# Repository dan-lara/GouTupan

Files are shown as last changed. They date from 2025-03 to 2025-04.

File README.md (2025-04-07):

# GouTupan



# User Guide —— GouTupan  

**Daniel, Vladislav, Xiaochen, Yulin**  

---

## Device Overview  

The system is an integrated environmental monitoring platform for agricultural greenhouses, based on an Arduino MKR WAN 1310 development board.  
Equipped with multiple specialized sensors, it enables real-time measurement of critical parameters for plant growth.  

Key features include:  
- Self-powered via solar panel with energy management circuit;  
- Waterproof design suitable for greenhouse environments with frequent irrigation;  
- Wireless data transmission via LoRaWAN;  
- Modular architecture for customized measurement points;  
- User interface: Web platform and local e-ink display for remote or on-site monitoring.  

---

## Installation and Usage Instructions  

The device transmits data using the LoRa protocol. Ensure the installation site has stable coverage from a LoRaWAN gateway.  
Without this, the following features will be unavailable: remote monitoring and historical data access.  

The system comprises four main modules:  
- **MCU Enclosure**: Contains the microcontroller and processing unit;  
- **"Mushroom" Sensor**: Measures ambient conditions;  
- **Soil Temperature & Humidity Sensor Array**;  
- **Solar Panel**: Powers the system.  

### MCU Enclosure  
Integrates an MKR WAN 1310 board, power management circuit, light sensor, and e-ink display.  
**Installation**: Position in a non-floodable area with direct ambient light exposure.  

### "Mushroom" Sensor  
Combines temperature, humidity, and gas sensors. Deploy at target measurement points.  
**Caution**: Avoid watering from below to prevent water ingress.  

### Soil Sensors  
- **Compact Probe**: Surface measurement (10 cm depth);  
- **Long Cylindrical Probe**: 50 cm length for deep soil measurements.  

### Solar Panel  
**Installation**: Place in a sunlit, elevated location to avoid water accumulation.  

### Activation  
Toggle the **side switch** on the MCU enclosure. Data transmission occurs every **3 minutes** (preconfigured).  

---

## Network and HMI Information  

### TTN (The Things Network)  
- **Username**: Levovitch  
- **Password**: demo1234  
- **Application Name**: `goutupan-mkr1310-vlad-xioa-dani-yuli`  
- **Device ID**: `goutupan-mkr1310-vlad-xioa-dani-yuli`  
- **AppEUI**: `AA2025AAAA2025AA`  
- **DevEUI**: `A8610A3234268310`  
- **AppKey**: `9qyh4jN6RBh4F@\$`  

### Useful Links  
- [Data Visualization Dashboard](https://goutupan.grafana.net/public-dashboards/d0bf3f14221d4401bc8c1fea2e30d045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)  
- [Project GitHub Repository](https://github.com/dan-lara/GouTupan)  

---

## Sensor Specifications  

**Table 1: Technical Specifications of Environmental Sensors**  

| Module | Measured Parameters | Technical Specifications |
|---|---|---|
| **SCD30** | Carbon Dioxide (CO₂),<br>Temperature,<br>Humidity | 400 ppm – 10,000 ppm (±30 ppm ±3%),<br>0–50 °C (±0.4 °C),<br>0–100% RH (±3% RH) |
| **TCS34725/SI1145** | Spectral Components (RGB/UV/IR) | λ = 465, 525, 615 nm,<br>Range: 400–1000 nm,<br>UV Detection: 280–400 nm (algorithmic)  |
| **SEN0605** | Nitrogen (N), Phosphorus (P), Potassium (K) | Range: 0–2999 mg/kg,<br>Resolution: 1 mg/kg,<br>Accuracy ≤5%,<br>IP68 |
| **Grove Barometer 101020068** | Barometric Pressure | 30–110 kPa (±0.01 hPa) |
| **SEN0322** | Oxygen (O₂) Concentration | 0–25% vol (drift < 2%/month) |
| **SGP40** | Volatile Organic Compounds (VOC) | VOC Index: 0–500,<br>Ethanol: 0–1000 ppm |
| **SHT30/SHT20** | Temperature & Humidity | Humidity: 0–100% RH (±2%RH/±3%RH),<br>Temperature: -40–125 °C (±0.2 °C/±0.3 °C) |
| **Grove Gas Sensor 101020820** | Ammonia (NH₃), <br>Carbon Monoxide (CO), <br>Nitrogen Dioxide (NO₂),<br>Propane (C₃H₈), <br>Butane (C₄H₁₀), <br>Methane (CH₄), <br>Hydrogen (H₂), <br>Ethanol (C₂H₅OH) | NH₃: 1–500 ppm,<br>CO: 5–5000 ppm,<br>NO₂: 0.05–2 ppm,<br>Hydrocarbons: 500–10,000 ppm,<br>H₂: 1–1000 ppm,<br>Ethanol: 1–500 ppm |

---

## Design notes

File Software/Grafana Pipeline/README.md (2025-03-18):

# DataFlow

Les codes dans ce dossier ont été utilisés pour la conception du MVP de notre solution. Les fichiers Python présents ici ont été utilisés pour créer une fonction Azure pour consommer les données de TTN et les envoyer à InfluxDB, qui sont consommées par un tableau de bord Grafana accessible via le lien : [grafana.danlara.com.br](http://grafana.danlara.com.br)

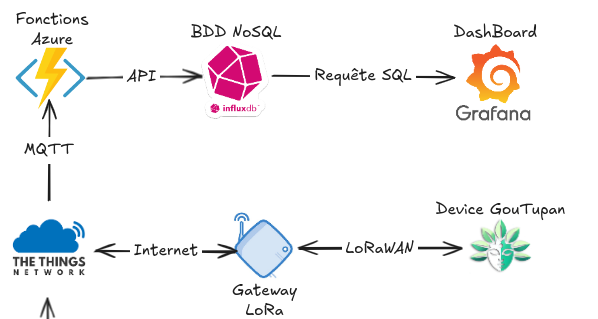
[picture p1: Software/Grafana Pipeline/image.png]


# Instalation

## Prérequis
Assurez-vous que le fichier `.env` est correctement rempli avec les informations nécessaires.

Les informations sont l'accès aux sujets MQTT de [The Things Network](https://www.thethingsnetwork.org/) de votre organisation et les données de votre organisation dans [InfluxDB](https://www.influxdata.com/).

## Étapes

1. **Créer un environnement virtuel**

    Ouvrez un terminal et naviguez jusqu'au dossier contenant les fichiers Python. Ensuite, exécutez les commandes suivantes :

    ```sh
    python3 -m venv venv
    ```

2. **Activer l'environnement virtuel**

    - Sur **Linux/MacOS** :

      ```sh
      source venv/bin/activate
      ```

    - Sur **Windows** :

      ```sh
      .\venv\Scripts\activate
      ```

3. **Installer les dépendances**

    Assurez-vous que vous êtes dans l'environnement virtuel activé, puis installez les dépendances nécessaires :

    ```sh
    pip install -r requirements.txt
    ```

4. **Exécuter les fichiers Python**

    Avec l'environnement virtuel activé, exécutez les fichiers Python :

    ```sh
    python ttn_influx_v1.py # MVP du 03/03/2025
    python ttn_influx_v2.py # Final Version
    ```

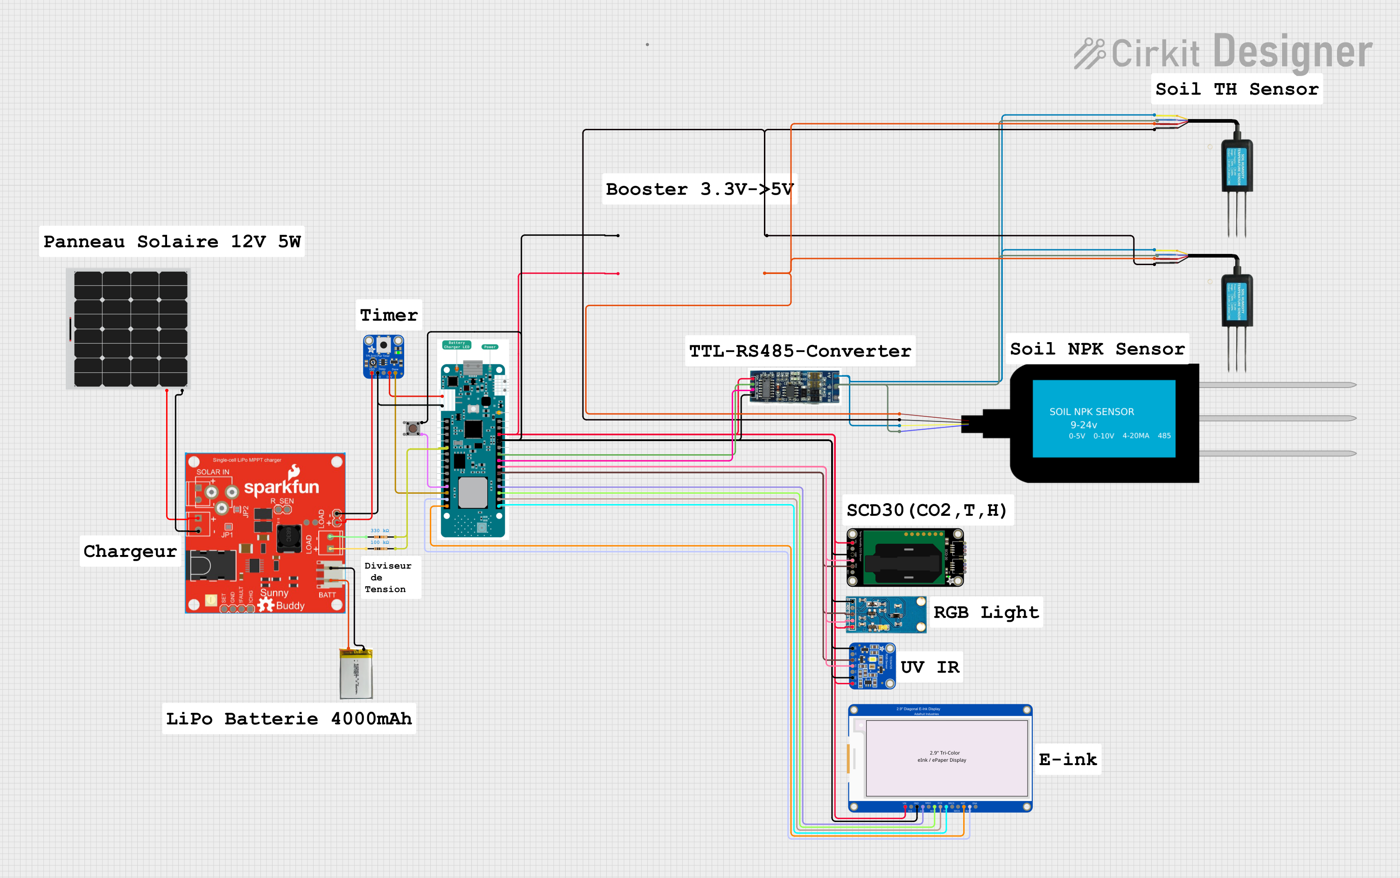
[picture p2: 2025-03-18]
Hardware/Circuit/circuit_image.png

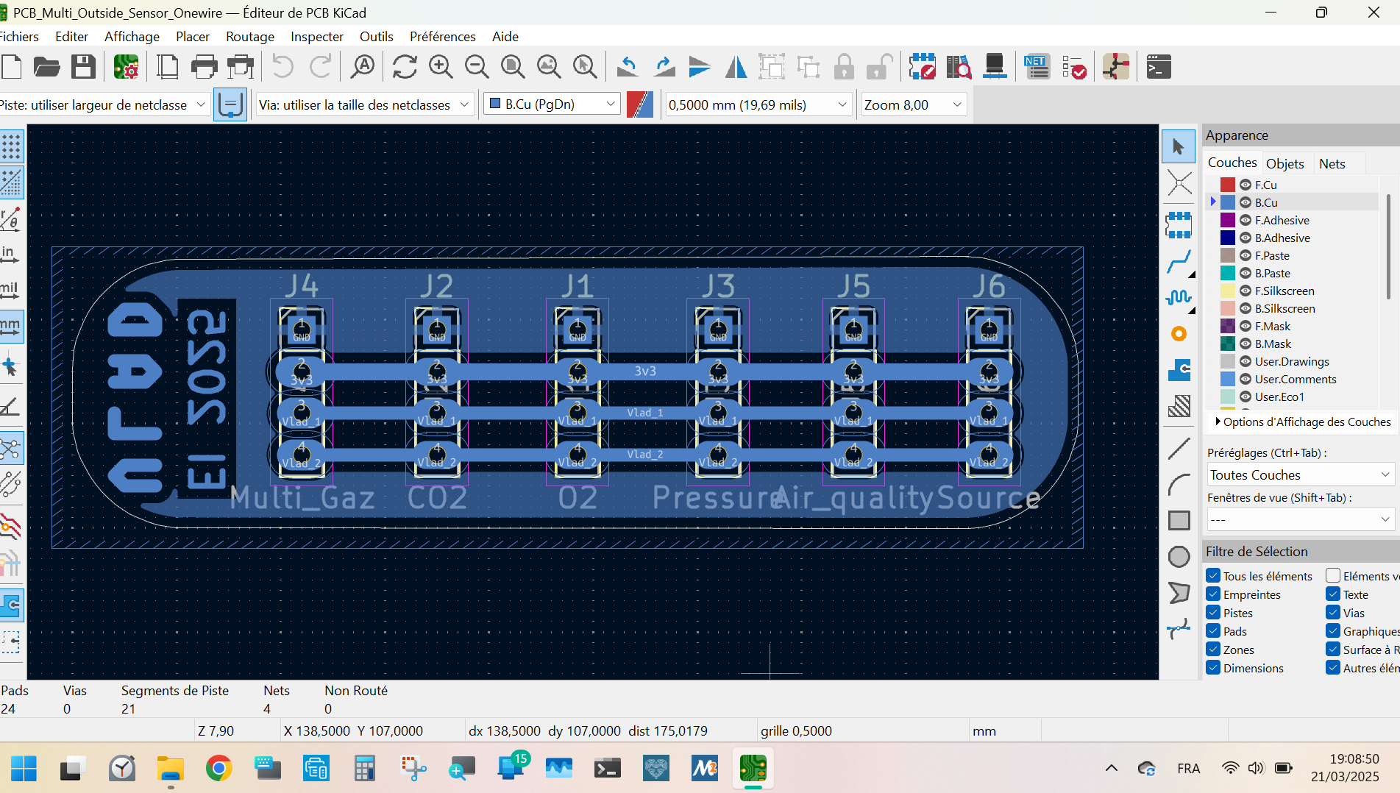
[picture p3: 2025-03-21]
Hardware/PCB_Multi_Outside_Sensor_Onewire/PCB_Kicad_v1.png

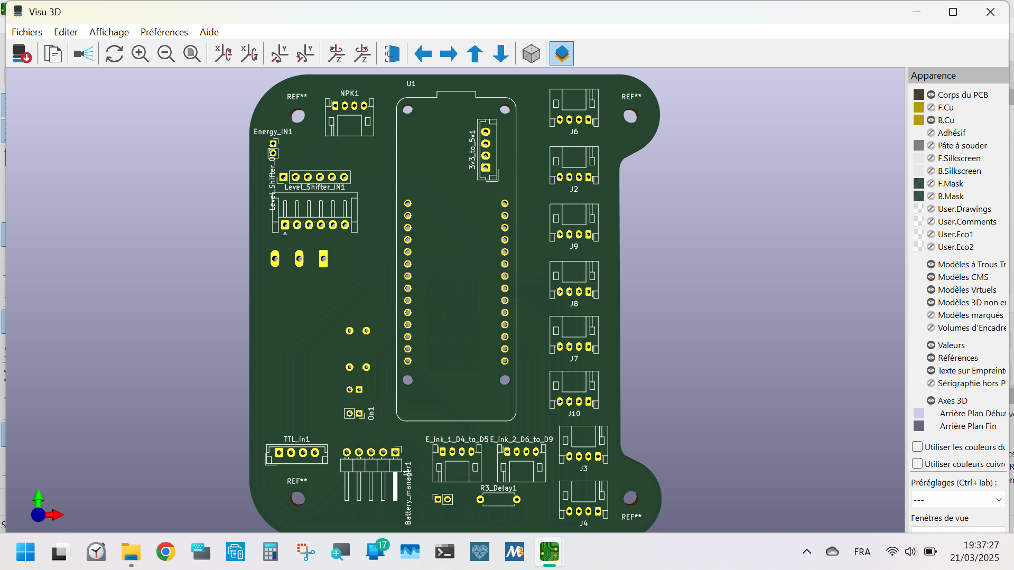
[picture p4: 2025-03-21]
Hardware/PCB_Main_Board/MKRWAN_NSK/PCB_3D_v4.png

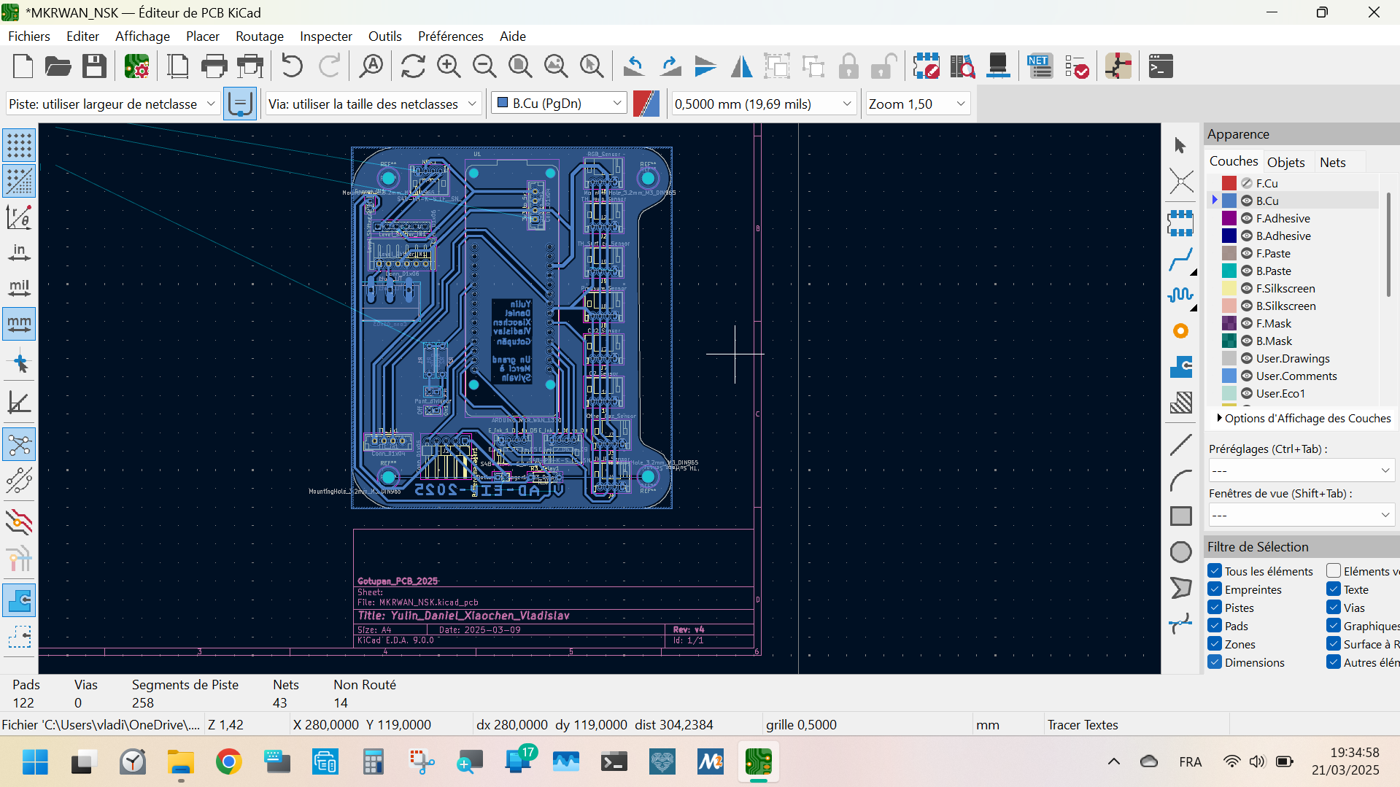
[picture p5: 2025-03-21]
Hardware/PCB_Main_Board/MKRWAN_NSK/PCB_Kicad_v4.png

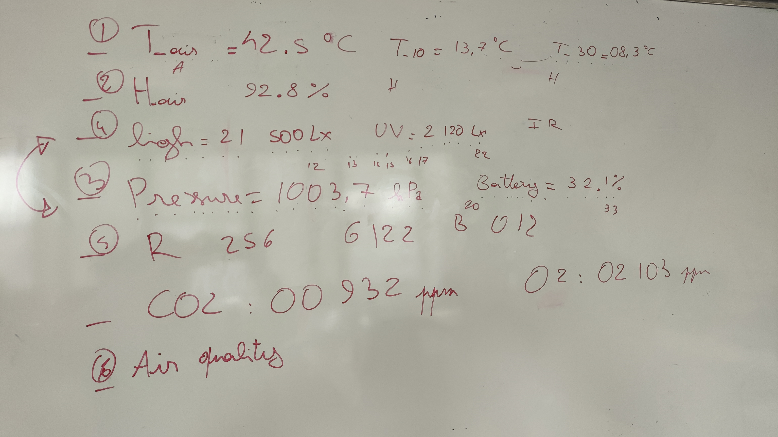
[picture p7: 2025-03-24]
Firmware/epd2in9b_V3/Data_Format.jpg

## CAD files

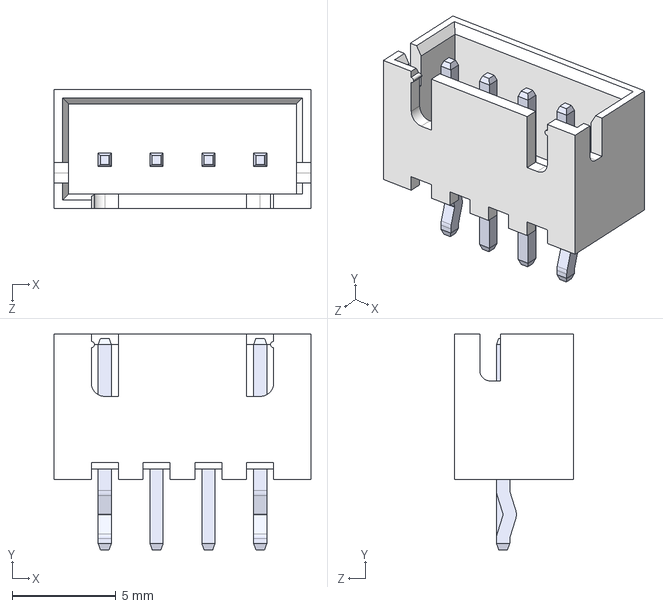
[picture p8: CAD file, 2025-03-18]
Hardware/PCB/B4B-XH-A_LF__SN_/B4B-XH-A_LF__SN_.step
12.4 x 10.4 x 5.75 mm

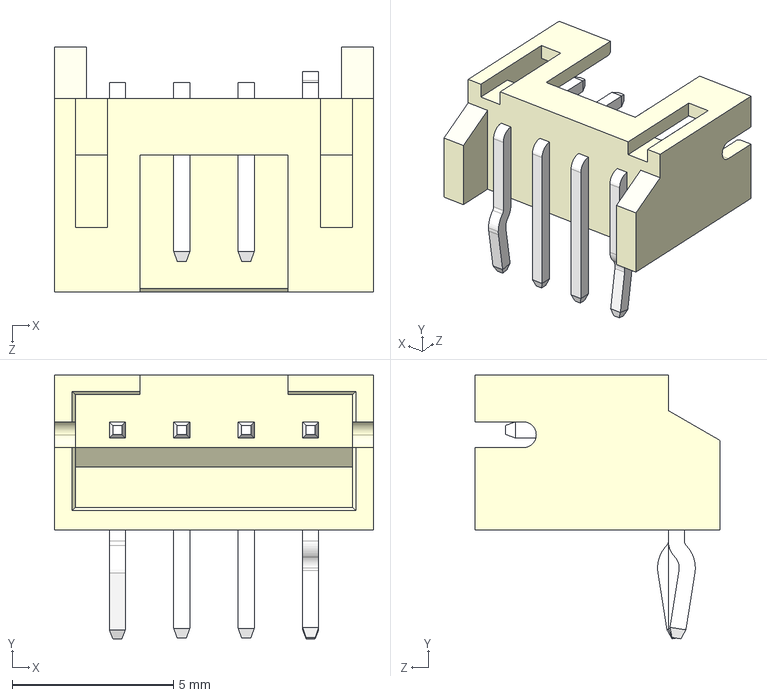
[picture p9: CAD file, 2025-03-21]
Hardware/PCB_Main_Board/S4B-PH-K-S_LF__SN_/S4B-PH-K-S_LF__SN_.step
9.90 x 8.18 x 7.60 mm

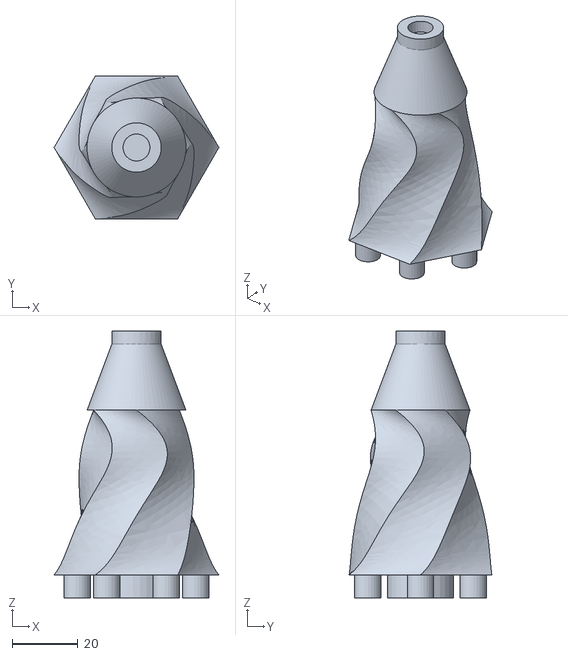
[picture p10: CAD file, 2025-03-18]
Mecanical/v10_bis_A_Sensor_House_Mushroom.stl
50.0 x 43.3 x 81.0

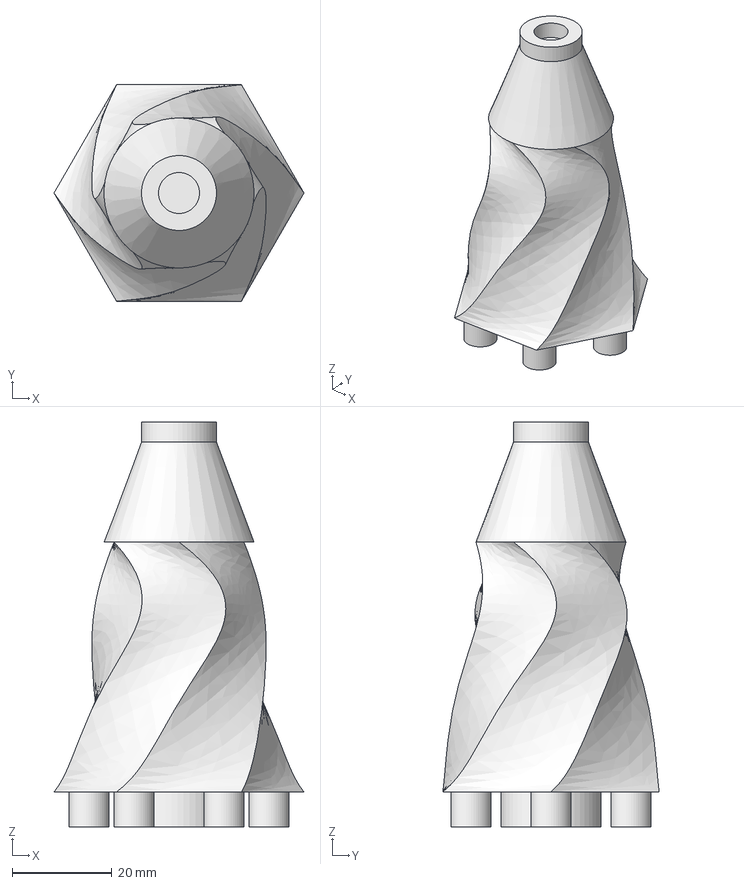
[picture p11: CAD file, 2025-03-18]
Mecanical/v10_A_Sensor_House_Mushroom.FCStd
50.0 x 43.3 x 81.0 mm

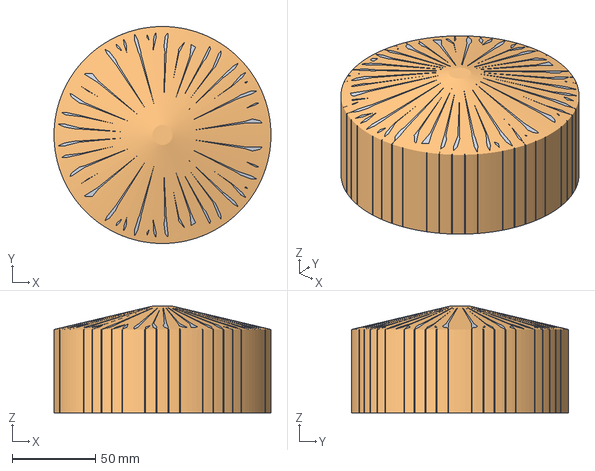
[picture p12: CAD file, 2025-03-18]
Mecanical/v10_B_Sensor_House_Mushroom.FCStd
130.0 x 130.0 x 64.0 mm
v10_B_Sensor_House_Mushroom-Part

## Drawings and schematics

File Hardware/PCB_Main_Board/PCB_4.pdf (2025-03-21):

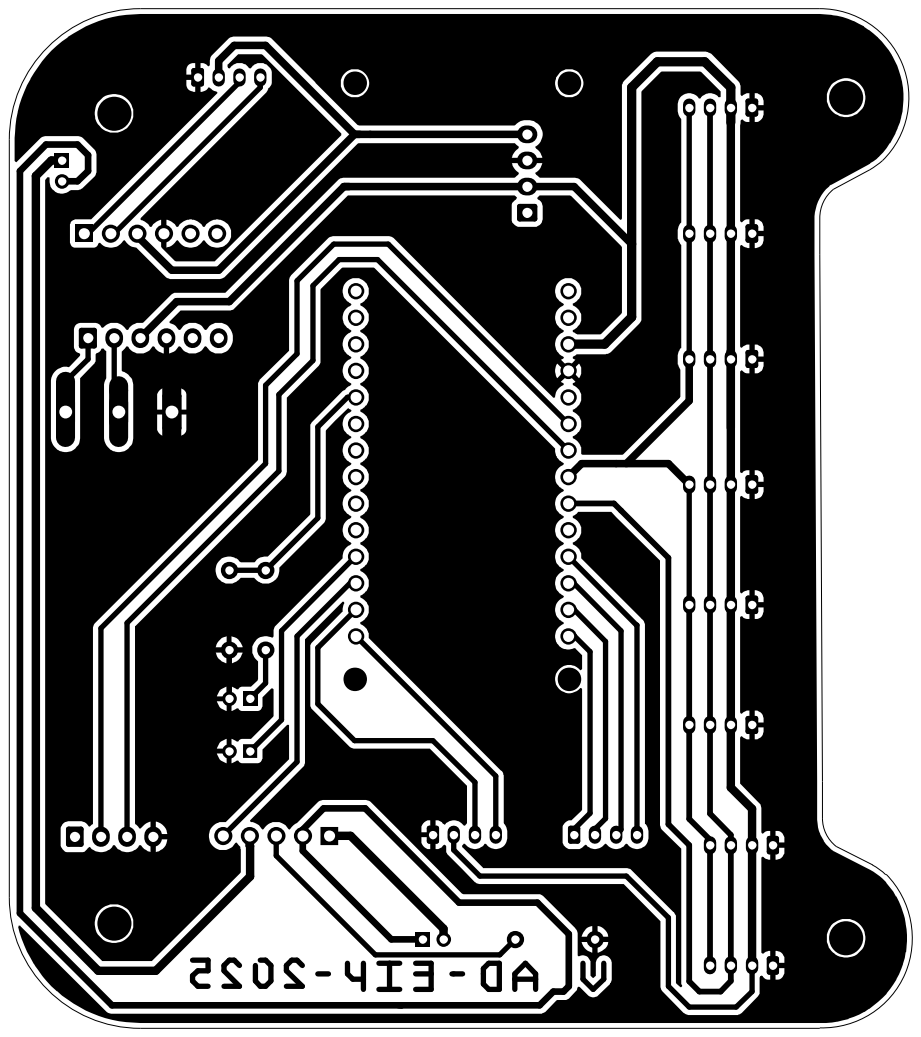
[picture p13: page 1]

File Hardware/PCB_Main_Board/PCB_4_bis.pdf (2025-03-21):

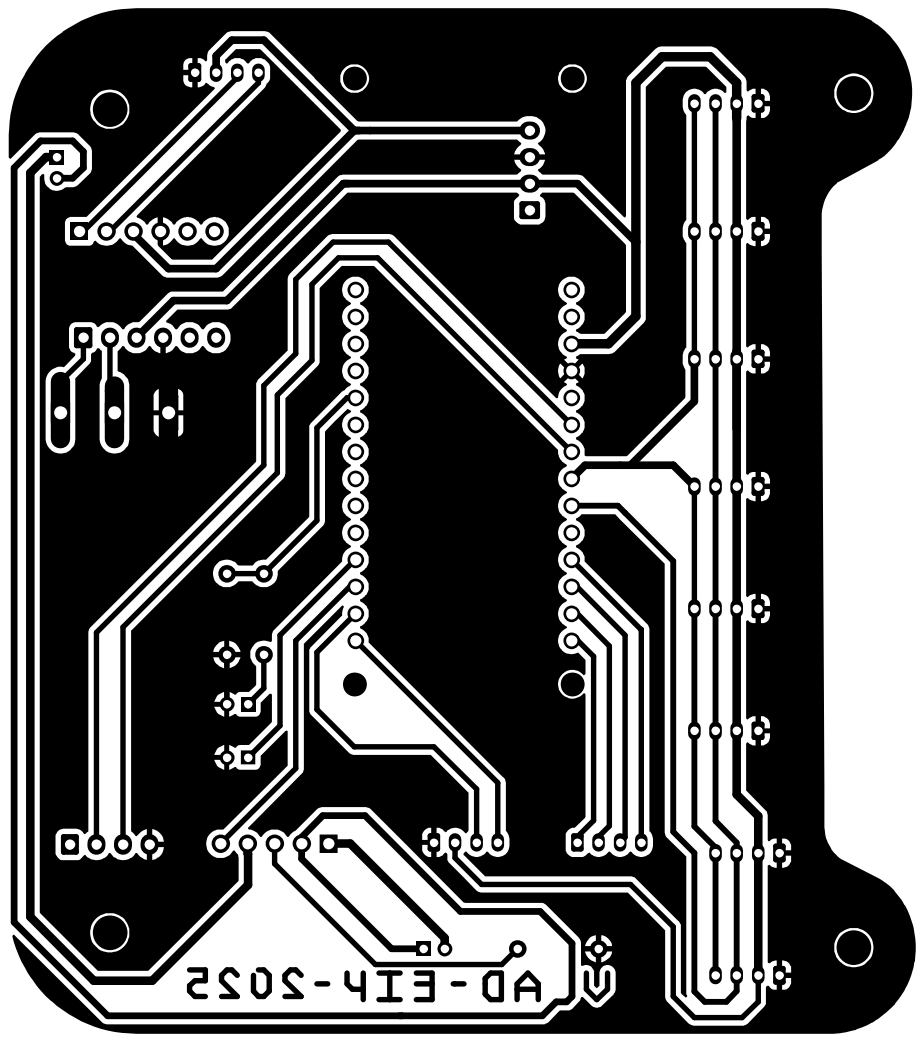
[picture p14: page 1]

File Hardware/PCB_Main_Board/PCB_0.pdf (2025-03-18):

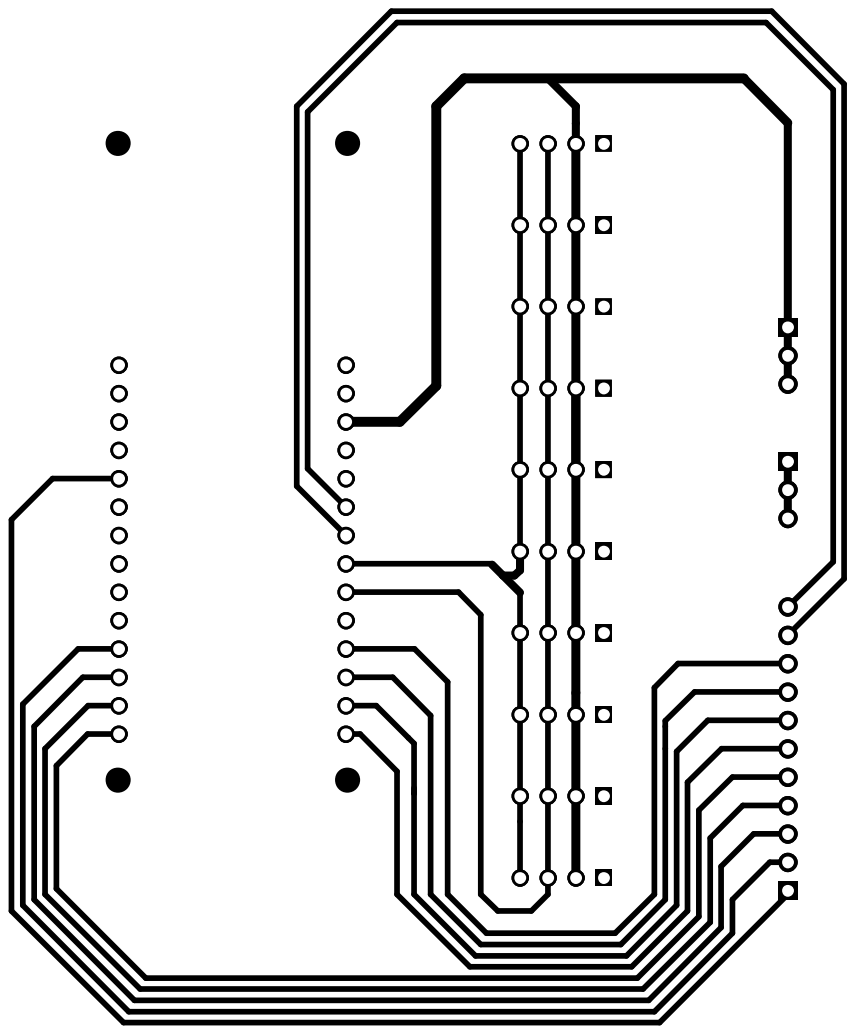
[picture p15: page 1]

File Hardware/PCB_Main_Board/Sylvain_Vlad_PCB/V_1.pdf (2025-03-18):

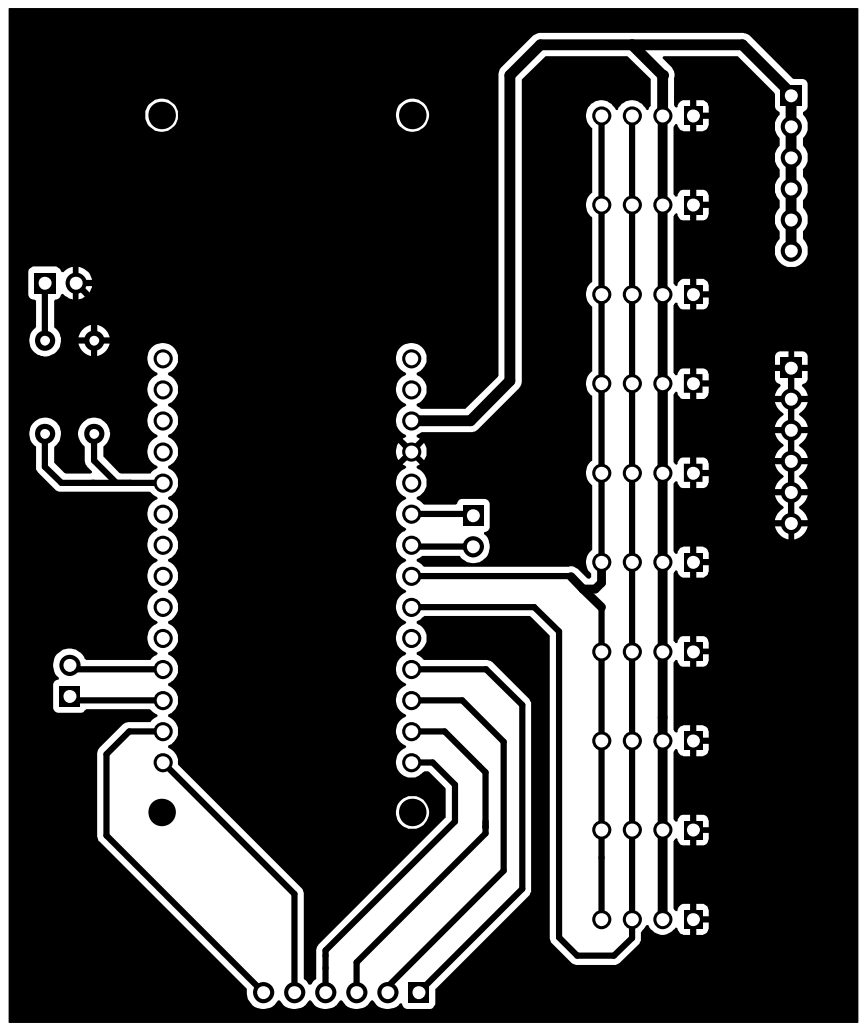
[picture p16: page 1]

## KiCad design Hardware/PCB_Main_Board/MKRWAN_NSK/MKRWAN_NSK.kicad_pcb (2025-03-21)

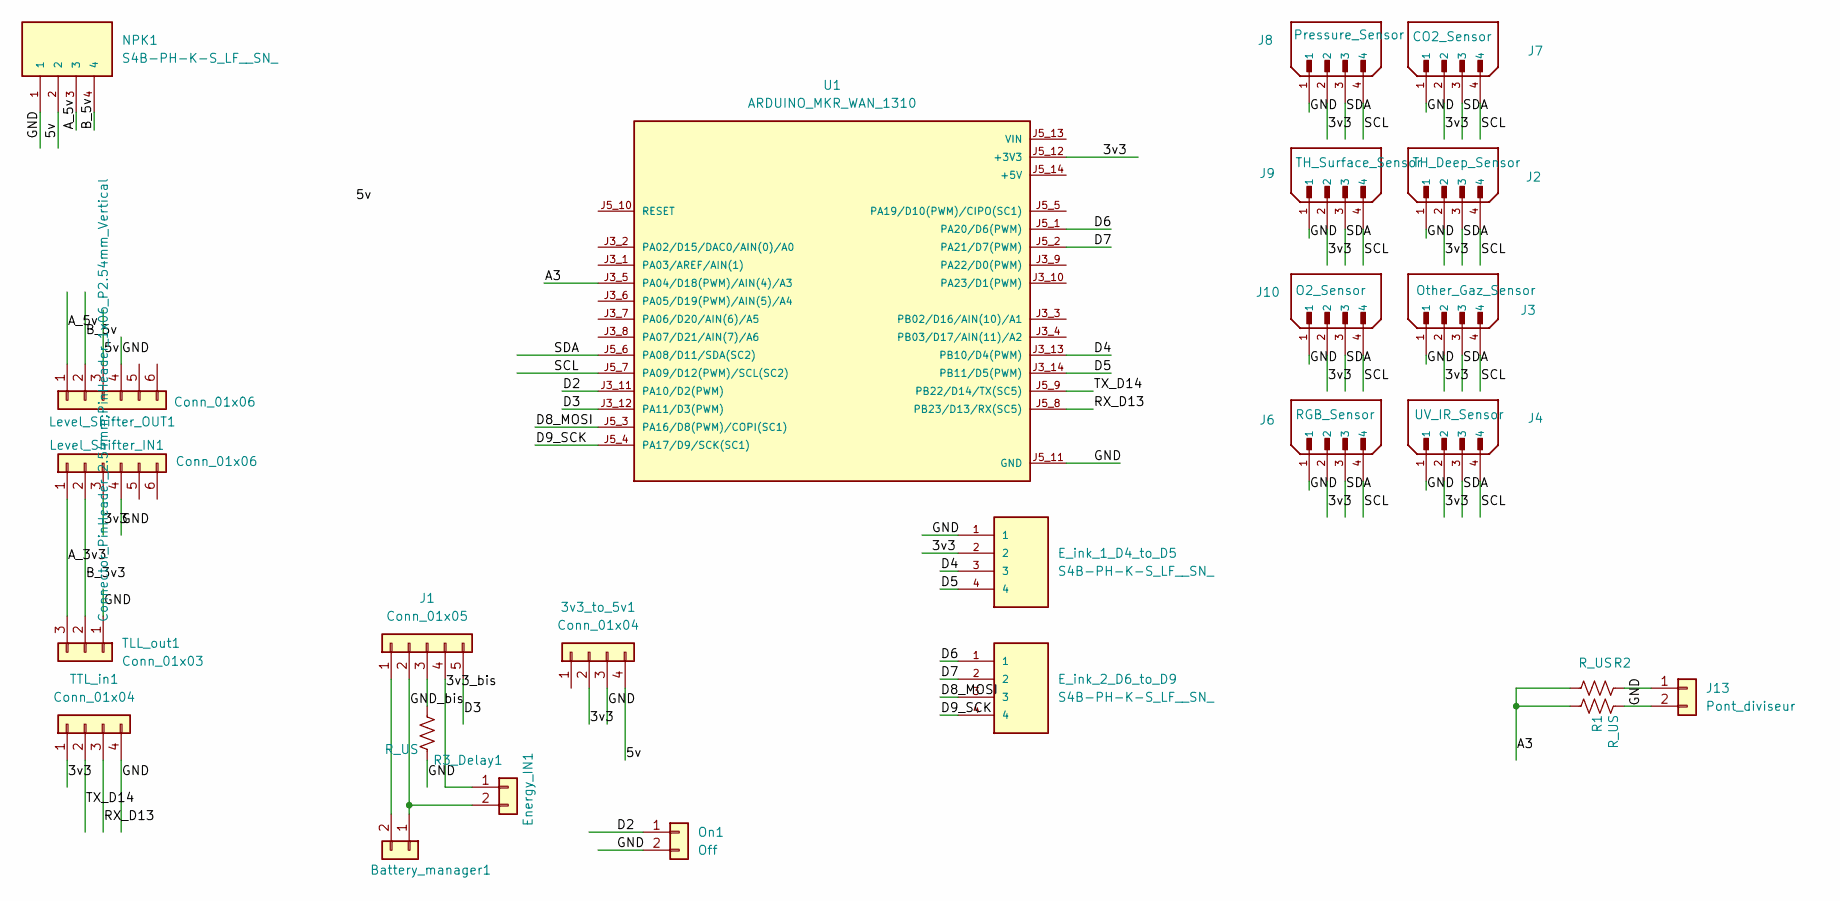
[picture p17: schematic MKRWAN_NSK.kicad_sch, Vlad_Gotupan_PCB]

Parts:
3v3_to_5v1: Conn_01x04; JST_EH_B4B-EH-A_1x04_P2.50mm_Vertical
Battery_manager1: PinSocket_1x02_P2.00mm_Vertical
E_ink_1_D4_to_D5, E_ink_2_D6_to_D9: S4B-PH-K-S_LF__SN_; JST_PH_S4B-PH-K_1x04_P2.00mm_Horizontal
Energy_IN1: Pont_diviseur; PinSocket_1x02_P2.00mm_Vertical
J1: Conn_01x05; PinHeader_1x05_P2.54mm_Horizontal
J2: TH_Deep_Sensor; JST_PH_S4B-PH-K_1x04_P2.00mm_Horizontal; PARTREV 7/4/21
J3: Other_Gaz_Sensor; JST_PH_S4B-PH-K_1x04_P2.00mm_Horizontal; PARTREV 7/4/21
J4: UV_IR_Sensor; JST_PH_S4B-PH-K_1x04_P2.00mm_Horizontal; PARTREV 7/4/21
J6: RGB_Sensor; JST_PH_S4B-PH-K_1x04_P2.00mm_Horizontal; PARTREV 7/4/21
J7: CO2_Sensor; JST_PH_S4B-PH-K_1x04_P2.00mm_Horizontal; PARTREV 7/4/21
J8: Pressure_Sensor; JST_PH_S4B-PH-K_1x04_P2.00mm_Horizontal; PARTREV 7/4/21
J9: TH_Surface_Sensor; JST_PH_S4B-PH-K_1x04_P2.00mm_Horizontal; PARTREV 7/4/21
J10: O2_Sensor; JST_PH_S4B-PH-K_1x04_P2.00mm_Horizontal; PARTREV 7/4/21
J13: Pont_diviseur; PinSocket_1x02_P2.00mm_Vertical
Level_Shifter_IN1: Conn_01x06; JST_EH_S6B-EH_1x06_P2.50mm_Horizontal
Level_Shifter_OUT1: Conn_01x06; PinHeader_1x06_P2.54mm_Vertical
NPK1: S4B-PH-K-S_LF__SN_; JST_PH_S4B-PH-K_1x04_P2.00mm_Horizontal
On1: Off; PinSocket_1x02_P2.00mm_Vertical
R1, R2, R3_Delay1: R_US; R_Axial_DIN0207_L6.3mm_D2.5mm_P7.62mm_Horizontal
TLL_out1: Conn_01x03; PhoenixContact_MC_1,5_3-G-5.08_1x03_P5.08mm_Horizontal
TTL_in1: Conn_01x04; JST_EH_B4B-EH-A_1x04_P2.50mm_Vertical
U1: ARDUINO_MKR_WAN_1310; BOARD_ARDUINO_MKR_WAN_1310; PARTREV 06/27/2019

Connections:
/3v3: 3v3_to_5v1.2, E_ink_1_D4_to_D5.2, J2.2, J3.2, J4.2, J6.2, J7.2, J8.2, J9.2, J10.2, Level_Shifter_IN1.3, TTL_in1.1, U1.J5_12 (+3V3)
/3v3_bis: Energy_IN1.1, J1.4
/5v: 3v3_to_5v1.4, Level_Shifter_OUT1.3, NPK1.2
/A3: R1.1, R2.2, U1.J3_5 (PA04/D18(PWM)/AIN(4)/A3)
/A_3v3: Level_Shifter_IN1.1, TLL_out1.3
/A_5v: Level_Shifter_OUT1.1, NPK1.3
/B_3v3: Level_Shifter_IN1.2, TLL_out1.2
/B_5v: Level_Shifter_OUT1.2, NPK1.4
/D2: On1.1, U1.J3_11 (PA10/D2(PWM))
/D3: J1.5, U1.J3_12 (PA11/D3(PWM))
/D4: E_ink_1_D4_to_D5.3, U1.J3_13 (PB10/D4(PWM))
/D5: E_ink_1_D4_to_D5.4, U1.J3_14 (PB11/D5(PWM))
/D6: E_ink_2_D6_to_D9.1, U1.J5_1 (PA20/D6(PWM))
/D7: E_ink_2_D6_to_D9.2, U1.J5_2 (PA21/D7(PWM))
/D8_MOSI: E_ink_2_D6_to_D9.3, U1.J5_3 (PA16/D8(PWM)/COPI(SC1))
/D9_SCK: E_ink_2_D6_to_D9.4, U1.J5_4 (PA17/D9/SCK(SC1))
/GND: 3v3_to_5v1.3, E_ink_1_D4_to_D5.1, J2.1, J3.1, J4.1, J6.1, J7.1, J8.1, J9.1, J10.1, J13.2, Level_Shifter_IN1.4, Level_Shifter_OUT1.4, NPK1.1, On1.2, R1.2, R3_Delay1.2, TLL_out1.1, TTL_in1.4, U1.J5_11 (GND)
/GND_bis: Battery_manager1.1, Energy_IN1.2, J1.2
/RX_D13: TTL_in1.3, U1.J5_8 (PB23/D13/RX(SC5))
/SCL: J2.4, J3.4, J4.4, J6.4, J7.4, J8.4, J9.4, J10.4, U1.J5_7 (PA09/D12(PWM)/SCL(SC2))
/SDA: J2.3, J3.3, J4.3, J6.3, J7.3, J8.3, J9.3, J10.3, U1.J5_6 (PA08/D11/SDA(SC2))
/TX_D14: TTL_in1.2, U1.J5_9 (PB22/D14/TX(SC5))
unnamed: Battery_manager1.2, J1.1
unnamed: J1.3, R3_Delay1.1
unnamed: J13.1, R2.1

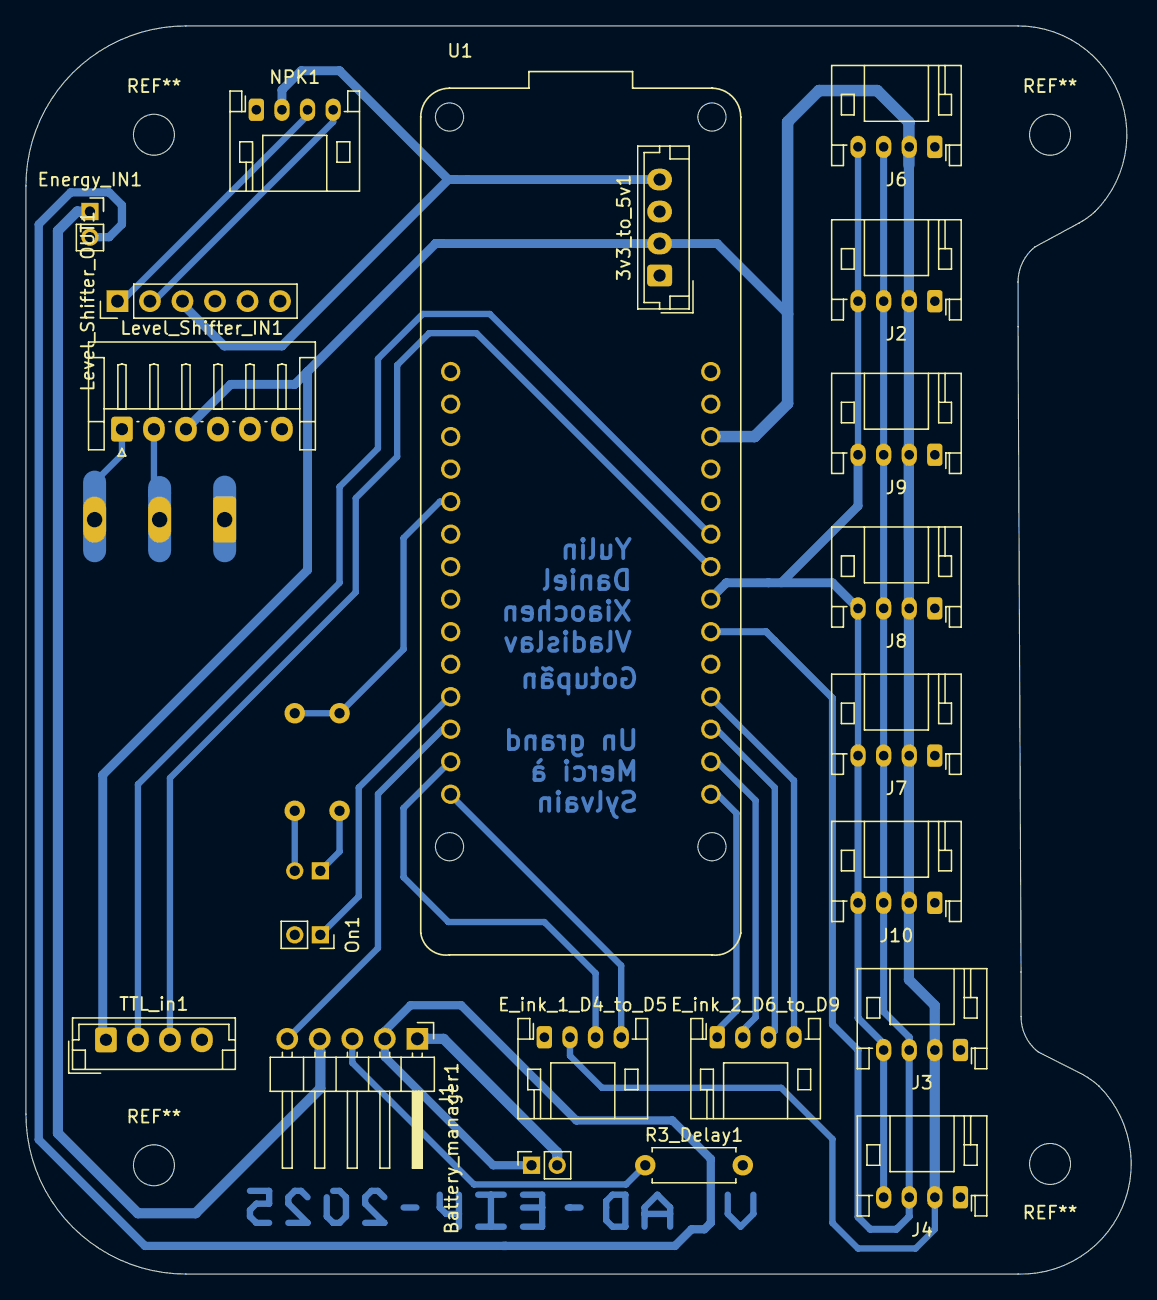
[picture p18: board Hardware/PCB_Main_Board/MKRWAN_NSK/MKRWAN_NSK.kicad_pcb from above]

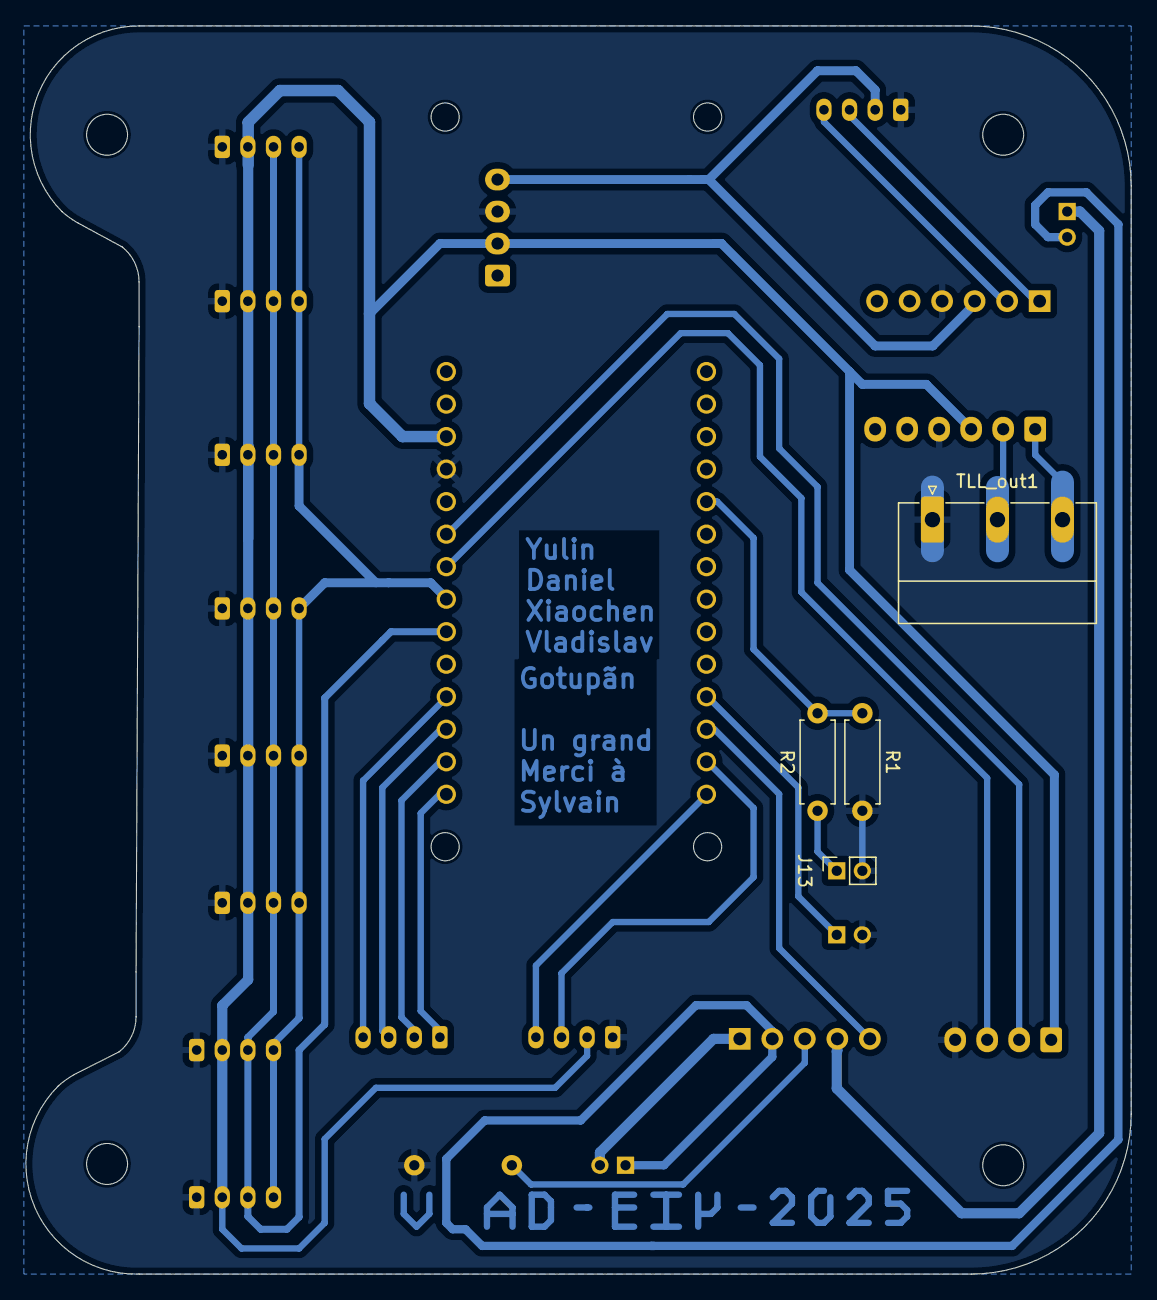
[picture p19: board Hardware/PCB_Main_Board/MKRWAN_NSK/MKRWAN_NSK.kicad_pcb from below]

Board: 2 copper layers, 86.3 x 97.5 mm, 25 parts (4 on the bottom side), 25 nets.

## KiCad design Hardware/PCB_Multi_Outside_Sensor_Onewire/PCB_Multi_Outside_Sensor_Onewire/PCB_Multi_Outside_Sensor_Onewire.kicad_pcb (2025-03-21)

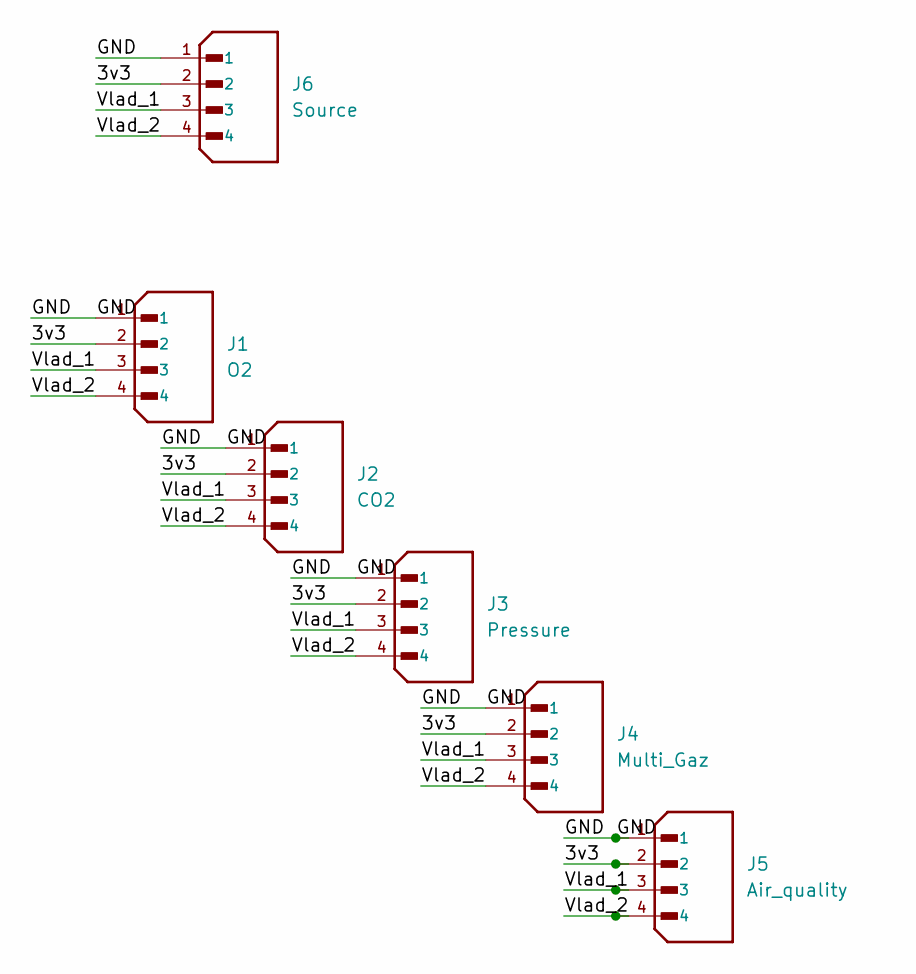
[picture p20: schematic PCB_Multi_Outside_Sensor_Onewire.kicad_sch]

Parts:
J1: O2; PinHeader_1x04_P2.00mm_Vertical; PARTREV 7/4/21
J2: CO2; PinHeader_1x04_P2.00mm_Vertical; PARTREV 7/4/21
J3: Pressure; PinHeader_1x04_P2.00mm_Vertical; PARTREV 7/4/21
J4: Multi_Gaz; PinHeader_1x04_P2.00mm_Vertical; PARTREV 7/4/21
J5: Air_quality; PinHeader_1x04_P2.00mm_Vertical; PARTREV 7/4/21
J6: Source; PinHeader_1x04_P2.00mm_Vertical; PARTREV 7/4/21

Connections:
/3v3: J1.2, J2.2, J3.2, J4.2, J5.2, J6.2
/GND: J1.1, J2.1, J3.1, J4.1, J5.1, J6.1
/Vlad_1: J1.3, J2.3, J3.3, J4.3, J5.3, J6.3
/Vlad_2: J1.4, J2.4, J3.4, J4.4, J5.4, J6.4

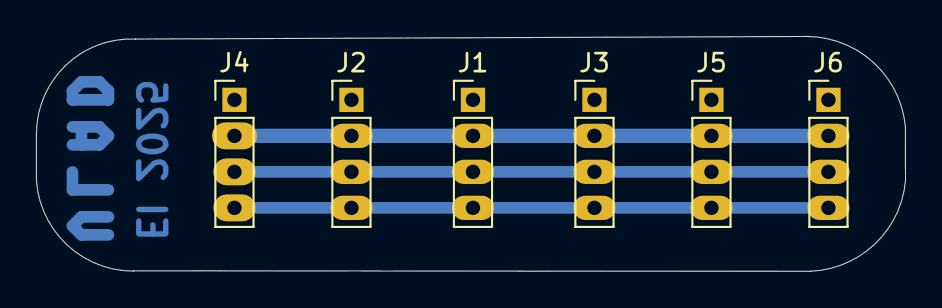
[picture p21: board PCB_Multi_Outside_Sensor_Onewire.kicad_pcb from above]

Board: 2 copper layers, 48.3 x 13.0 mm, 6 parts (0 on the bottom side), 4 nets.

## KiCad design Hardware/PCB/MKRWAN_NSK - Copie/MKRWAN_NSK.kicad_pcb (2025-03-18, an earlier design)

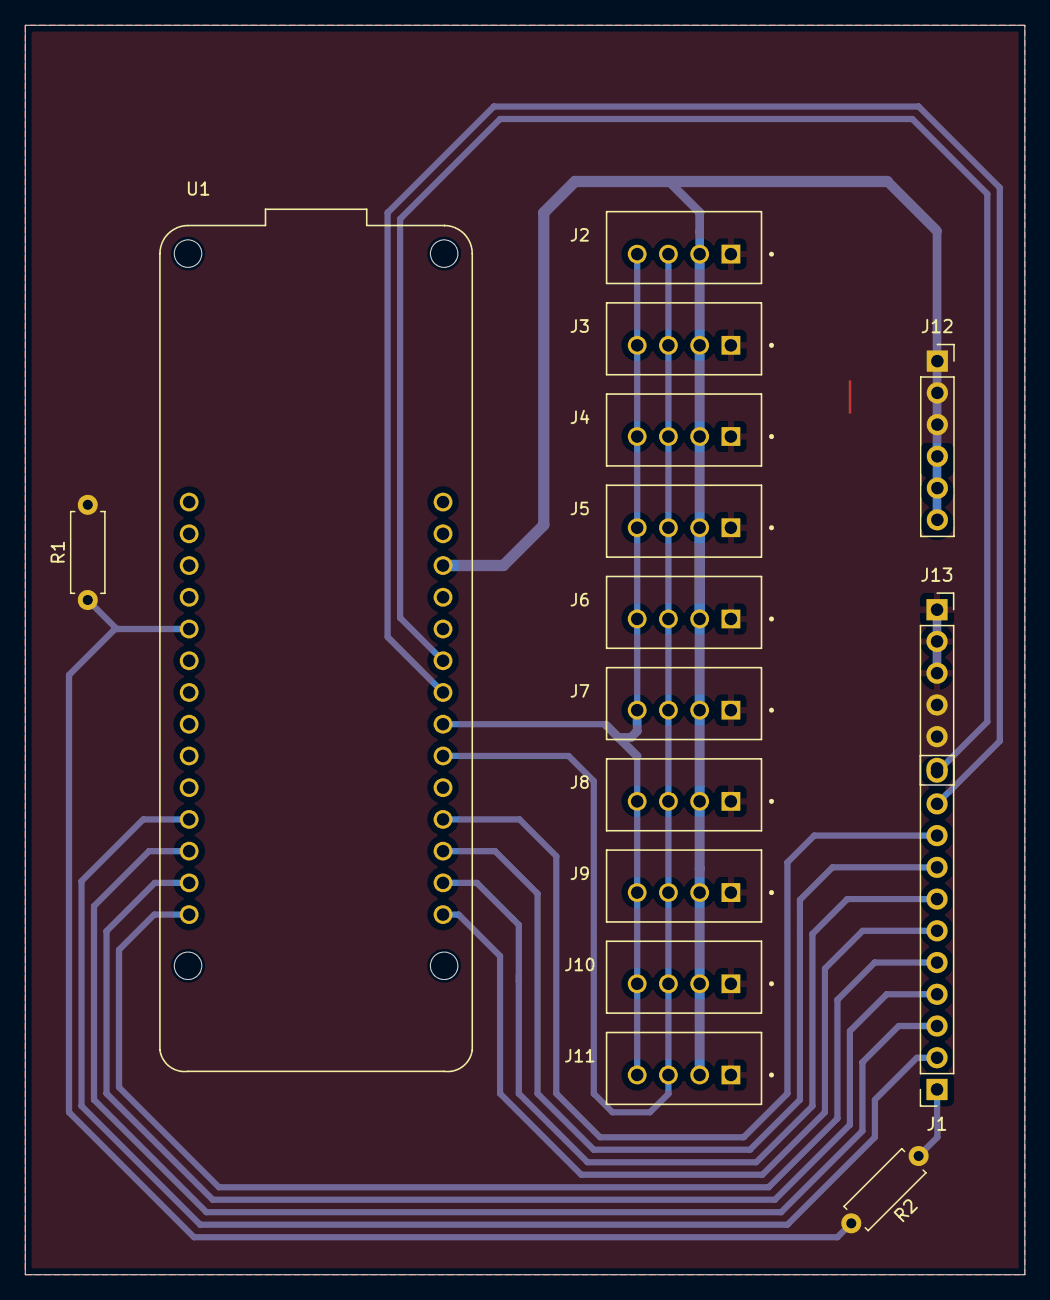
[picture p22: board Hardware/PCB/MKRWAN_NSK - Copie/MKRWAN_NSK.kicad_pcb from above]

Board: 2 copper layers, 80.0 x 100.0 mm, 16 parts (0 on the bottom side), 16 nets.

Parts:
J1: Conn_01x11; PinSocket_1x11_P2.54mm_Vertical
J2: TH_Deep_Sensor; JST_B4B-XH-A_LF__SN_
J3: Other_Gaz_Sensor; JST_B4B-XH-A_LF__SN_
J4: UV_IR_Sensor; JST_B4B-XH-A_LF__SN_
J5: Extra_2; JST_B4B-XH-A_LF__SN_
J6: RGB_Sensor; JST_B4B-XH-A_LF__SN_
J7: CO2_Sensor; JST_B4B-XH-A_LF__SN_
J8: Pressure_Sensor; JST_B4B-XH-A_LF__SN_
J9: TH_Surface_Sensor; JST_B4B-XH-A_LF__SN_
J10: O2_Sensor; JST_B4B-XH-A_LF__SN_
J11: Extra_1; JST_B4B-XH-A_LF__SN_
J12: 3v3; PinSocket_1x06_P2.54mm_Vertical
J13: GND; PinSocket_1x06_P2.54mm_Vertical
R1, R2: R_US; R_Axial_DIN0207_L6.3mm_D2.5mm_P7.62mm_Horizontal
U1: ARDUINO_MKR_WAN_1310; BOARD_ARDUINO_MKR_WAN_1310

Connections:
/3v3: J2.2, J3.2, J4.2, J5.2, J6.2, J7.2, J8.2, J9.2, J10.2, J11.2, J12.1, J12.2, J12.3, U1.J5_12 (+3V3)
/A3: R1.1, R2.2, U1.J3_5 (PA04/D18(PWM)/AIN(4)/A3)
/D2: J1.2, U1.J3_11 (PA10/D2(PWM))
/D3: J1.3, U1.J3_12 (PA11/D3(PWM))
/D4: J1.4, U1.J3_13 (PB10/D4(PWM))
/D5: J1.5, U1.J3_14 (PB11/D5(PWM))
/D6: J1.6, U1.J5_1 (PA20/D6(PWM))
/D7: J1.7, U1.J5_2 (PA21/D7(PWM))
/D8_MOSI: J1.8, U1.J5_3 (PA16/D8(PWM)/COPI(SC1))
/D9_SCK: J1.9, U1.J5_4 (PA17/D9/SCK(SC1))
/GND: J2.1, J3.1, J4.1, J5.1, J6.1, J7.1, J8.1, J9.1, J10.1, J11.1, J13.1, J13.2, J13.3, R1.2
/RX_D13: J1.10, U1.J5_8 (PB23/D13/RX(SC5))
/SCL: J2.4, J3.4, J4.4, J5.4, J6.4, J7.4, J8.4, J9.4, J10.4, J11.4, U1.J5_7 (PA09/D12(PWM)/SCL(SC2))
/SDA: J2.3, J3.3, J4.3, J5.3, J6.3, J7.3, J8.3, J9.3, J10.3, J11.3, U1.J5_6 (PA08/D11/SDA(SC2))
/TX_D14: J1.11, U1.J5_9 (PB22/D14/TX(SC5))
unnamed: J1.1, R2.1

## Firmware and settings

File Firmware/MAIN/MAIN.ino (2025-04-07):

// Read_and_Send.ino
#define TEST_MODE 0        // Set to 1 to enable Serial Monitor debugging, 0 to disable

#include <ArduinoLowPower.h> // Break low power mode

//LoRa
#include "LoRa_Transmission.hpp"

//CO2 + T/H
#include <Adafruit_SCD30.h>
Adafruit_SCD30  scd30;

//Pressure
    #include "Baroleter_High_Accuracy.hpp"

//RGB
    #include "ColorSensor.hpp"

//Pressure
    #include "Baroleter_High_Accuracy.hpp"

//RGB
    #include "ColorSensor.hpp"

//Humidity soil
    //#include "DFRobot_SEN0308.hpp"
    //#define SENSOR_PIN A1   //30cm
    //#define SENSOR_PIN2 A2  //10cm
    //SoilMoistureSensor_SEN0308 cap;
    //SoilMoistureSensor_SEN0308 cap2;

//Soil Temperatur + Humidity
    #include "SHT3xSensor.hpp"
    SHT3xSensor SHT3xsensor(0x44, &Wire); // 使用默认地址0x44和Wire
    #include "DFRobot_SHT20.h"
    DFRobot_SHT20 sht20(&Wire, SHT20_I2C_ADDR);


//Battery
    #include "BatteryManager.hpp"
    #define ANALOG_PIN A3
    #define CHARGE_PIN 7
    #define FAULT_PIN 6
    BatteryManager batman;

//Multi GAZ
    #include "Multi_Gaz.hpp"

//UV + IR 
    #include "SI114X.hpp"
    Adafruit_SI1145 SI1145 = Adafruit_SI1145();


//Air Quality
    #include "SEN0394_Air_Quality.hpp"
    AirSensor airSensor;

//O2 Sensor
    #include "SEN0332_O2.hpp"
    DFRobot_OxygenSensor oxygen;

//Timer
    #define DONE_PIN 3  // TPL5110 DONE 连接到 Arduino D2

// E-ink
    #include <SPI.h>
    #include "epd2in9b_V3.hpp"
    #include "epd_text.hpp"
    Epd epd;
    EpdText epdText(epd);

//NPK
    #include "NPK.hpp"

#define TEST_MODE 0        // Set to 1 to enable Serial Monitor debugging, 0 to disable
#define NB_MAX_SENSOR_ATTEMPT 10
long int t=0;

void setup() 
{
    delay(1000);

    #if TEST_MODE
      t = millis();  
      Serial.begin(115200);
      Serial.println("START");

    #endif
    
    //setup Timer
    pinMode(DONE_PIN, OUTPUT);
    digitalWrite(DONE_PIN, LOW); // 初始状态，DONE 置低
    

    // // E-ink
    // #if TEST_MODE
    // Serial.print("2.9inch b V3 e-Paper init \r\n ");
    // #endif
    // // if(flag == false){
    //   if (epd.Init() != 0) 
    //   {
    //       #if TEST_MODE
    //         Serial.print("e-Paper init failed\r\n ");
    //       #endif
    //       return;
    //   }
    // // }
    // epd.Clear();

// LoRa
    #if TEST_MODE
      Serial.println("Begining LoRa");
    #endif
    initializeLoRa();
    #if TEST_MODE
      Serial.println("LoRa Initialized");
    #endif

// Sensors Setup
    
    // CO2 + T/H
     int attempts = 0;
    while (!scd30.begin() && attempts < NB_MAX_SENSOR_ATTEMPT) 
    {
        #if TEST_MODE
            Serial.println("Tentative de connexion au capteur CO2...");
        #endif
        delay(400);  // Attendre 1 seconde avant de réessayer
        attempts++;
    }

    // Pressure
    setupBarometer(); 
    float pressure_test = getPressure();

    // RGB
    attempts = 0;
    while (!initColorSensor() && attempts < NB_MAX_SENSOR_ATTEMPT) 
    {
        #if TEST_MODE
            Serial.println("ERROR: Color sensor not detected!");
        #endif
        delay(400); 
        attempts++;
    }

    // Humidity soil
    //attempts = 0;
    //while (cap2.begin(SENSOR_PIN2) && attempts < NB_MAX_SENSOR_ATTEMPT) 
    //{
    //    #if TEST_MODE
    //        Serial.println("Sensor initialized successfully.");
    //    #endif
    //    delay(400); 
    //    attempts++;
    //}

    // UV + IR
    attempts = 0;
    while (!SI1145.begin() && attempts < NB_MAX_SENSOR_ATTEMPT) 
    {
        #if TEST_MODE
            Serial.println("ERROR: Si1145 is not detected!");
        #endif
        delay(400); 
        attempts++;
    }

    // Soil Temperatur + Humidity
    attempts = 0;
    while (!SHT3xsensor.begin() && attempts < NB_MAX_SENSOR_ATTEMPT) 
    {
        #if TEST_MODE
            Serial.println("ERROR: SHT3x sensor not detected!");
        #endif
        delay(400); 
        attempts++;
    }

    attempts = 0;
    sht20.initSHT20();
    // while (!sht20.initSHT20() && attempts < NB_MAX_SENSOR_ATTEMPT) 
    // {
    //     #if TEST_MODE
    //         Serial.println("ERROR: SHT20 sensor not detected!");
    //     #endif
    //     delay(400); 
    //     attempts++;
    // }

    // Battery
    batman.begin(ANALOG_PIN, CHARGE_PIN, FAULT_PIN);
    setupGasSensor();

    // Air Quality
    airSensor.begin(NB_MAX_SENSOR_ATTEMPT);
    oxygen.setup_O2_sensor(NB_MAX_SENSOR_ATTEMPT);

    // // // E-ink
    #if TEST_MODE
    Serial.print("2.9inch b V3 e-Paper init \r\n ");
    #endif
    if (epd.Init() != 0) {          // Échec de l'initialisation (y compris le délai d'attente ou l'erreur matérielle)
        epd.eink_failed = true;     // Forcer l'indicateur de synchronisation
        #if TEST_MODE
            Serial.println("FAILED. Skipping E-ink.");
        #endif
    } else {
        #if TEST_MODE
            Serial.println("SUCCESS.");
        #endif
        //epd.Clear();               // Effacer l'écran uniquement en cas de succès
    }


    // NPK
    #if TEST_MODE
        Serial.println("Tentative de connexion au capteur NPK...");
    #endif
    Serial1.begin(9600);

    #if TEST_MODE
        Serial.print("Setup completed in: ");
        Serial.print(millis() - t);
        Serial.print(" ms ==> ");
        Serial.print((millis() - t) / 1000);
        Serial.println(" s");
        Serial.println("---------------------------------------------------------");
    #endif
    // pinMode(LED_BUILTIN, OUTPUT);
    delay(2000);
    // digitalWrite(LED_BUILTIN, HIGH);  // Liga o LED
    // delay(500);                       // Espera 500ms
    // digitalWrite(LED_BUILTIN, LOW);   // Desliga o LED
    // delay(500);
}

void loop() 
{
    // Example of sending temperature data (approximately 38.9°C)
    uint8_t mux_code = 0x1; // Sending 1 data
    float outside_temperature = -7.5865; // °C
    float outside_humidity = 49.85423; // %
    float outside_CO2 = 3220.53; // ppm

    // CO2 + T/H
    if (scd30.dataReady()) 
    {
        if (scd30.read()) 
        {
            // Mise à jour des valeurs avec celles lues du capteur
            outside_temperature = scd30.temperature;
            outside_humidity = scd30.relative_humidity;
            outside_CO2 = scd30.CO2;
        }
    }
    #if TEST_MODE
    {
      t = millis();
        Serial.println("==================================================================");
        Serial.println("==========================Test Mode===============================");
        Serial.print("Temperature: ");
        Serial.print(outside_temperature, 1);   // Only print one decimal place
        Serial.print("C");
        Serial.print(" Humidity: ");
        Serial.print(outside_humidity, 1);   // Only print one decimal place
        Serial.print("%");
        Serial.print(" CO2: ");
        Serial.print(outside_CO2, 1);   // Only print one decimal place
        Serial.println("ppm");
    }
    #endif
    // Battery

    //float voltage = batman.read(false);
    //bool charging = batman.isCharging();
    //bool fault = batman.isFault();

    //float battery_level = batman.read(); // % Voltage
    float battery_level = batman.read(true); // % Voltage
    #if TEST_MODE
      Serial.print("Battery Level:");
      Serial.print(battery_level, 1);
      Serial.println("%");
    #endif

    // Soil Nutrients
    float soil_nutrients_N_Nitrogen = 198.29; // ppm
    float soil_nutrients_P_Phosphorus = 13.22; // ppm
    float soil_nutrients_K_Potassium = 287.99; // ppm

    soil_nutrients_N_Nitrogen = read_NPK_N_Nitrogen();  // ppm
    soil_nutrients_P_Phosphorus = read_NPK_P_Phosphorus();  // ppm
    soil_nutrients_K_Potassium = read_NPK_K_Potassium();  // ppm

    #if TEST_MODE
        Serial.print("N = ");
        Serial.print(soil_nutrients_N_Nitrogen);
        Serial.print(" mg/kg  ");

        Serial.print("P = ");
        Serial.print(soil_nutrients_P_Phosphorus);
        Serial.print(" mg/kg  ");

        Serial.print("K = ");
        Serial.print(soil_nutrients_K_Potassium);
        Serial.println(" mg/kg  ");
    #endif
    

    // Soil Temperatur + Humidity
    //float surface_temperature = 8.58; // °C
    //float surface_humidity = cap2.read(); // %

    // SHT3x
    auto data_SHT3xsensor = SHT3xsensor.measure();
    float deep_temperature = data_SHT3xsensor.first;
    float deep_humidity = data_SHT3xsensor.second;
    // SHT20
    float surface_temperature = sht20.readTemperature();
    float surface_humidity = sht20.readHumidity();
    
    #if TEST_MODE
      Serial.print("SHT30 Temperature:");
      Serial.print(deep_temperature, 1);   // Only print one decimal place
      Serial.print("C");
      Serial.print(" SHT30 Humidity:");
      Serial.print(deep_humidity, 1);   // Only print one decimal place
      Serial.print("%");
      Serial.println();
      
      Serial.print("SHT20 Temperature:");
      Serial.print(surface_temperature, 1);   // Only print one decimal place
      Serial.print("C");
      Serial.print(" SHT20 Humidity:");
      Serial.print(surface_humidity, 1);   // Only print one decimal place
      Serial.print("%");
      Serial.println();
    #endif
    //RGB
    float R_RGB, G_RGB, B_RGB, light_intensity;

    readAndNormalizeColor(&R_RGB, &G_RGB, &B_RGB, &light_intensity);

    #if TEST_MODE
      Serial.println("TCS34725 RGB Color Sensor");
      Serial.print("R: ");
      Serial.print(R_RGB);
      Serial.print(" G: ");
      Serial.print(G_RGB);
      Serial.print(" B: ");
      Serial.print(B_RGB);
      Serial.print(" Light Intensity: ");
      Serial.println(light_intensity);
    #endif

    uint16_t light_infrared = 0;
    light_infrared = SI1145.readIR();
    float light_ultraviolet, light_intesity_SI1145;
    light_ultraviolet = (float)(SI1145.readUV())/100;
    light_intesity_SI1145 = (float)SI1145.readVisible();

    #if TEST_MODE
      Serial.println("SI1145 UV/IR Sensor");
      Serial.print("Vis: "); Serial.println(light_intesity_SI1145);
      Serial.print("IR: "); Serial.println(light_infrared);
      Serial.print("UV: "); Serial.println(light_ultraviolet);
    #endif

    float pressure = getPressure();
    float quality = airSensor.readAirQuality();
    float O2 = oxygen.getOxygenData(10);

    #if TEST_MODE
      Serial.print("Pressure : ");
      Serial.println(pressure);
      Serial.print("Air Quality (VOC) : ");
      Serial.println(quality);
      if (quality >= 0 && quality <= 100) {
        Serial.println("Air Quality: Excellent. No need to ventilate or purify.");
      } else if (quality > 100 && quality <= 200) {
        Serial.println("Air Quality: Good. No need to ventilate or purify.");
      } else if (quality > 200 && quality <= 400) {
        Serial.println("Air Quality: Moderate. Ventilate and purify.");
      } else if (quality > 400 && quality <= 500) {
        Serial.println("Air Quality: Poor. Ventilate and purify intensely.");
      } else {
        Serial.println("Air Quality: Out of range. Check sensor.");
      }
      Serial.print("O2 : ");
      Serial.print(O2);
      Serial.print(" ppm <==> ");
      Serial.print(O2/10000);
      Serial.println(" \%Vol");
    #endif

    float nh3, co, no2, c3h8, c4h10, ch4, h2, c2h5oh;
    readGasValues(&nh3, &co, &no2, &c3h8, &c4h10, &ch4, &h2, &c2h5oh);

    #if TEST_MODE
      Serial.print("NH3: ");
      Serial.print(nh3);
      Serial.print(" ppm");
      Serial.print(" CO: ");
      Serial.print(co);
      Serial.print(" ppm");
      Serial.print(" NO2: ");
      Serial.print(no2);
      Serial.print(" ppm");
      Serial.print(" C3H8: ");
      Serial.print(c3h8);
      Serial.println(" ppm");
      Serial.print("C4H10: ");
      Serial.print(c4h10);
      Serial.print(" ppm");
      Serial.print(" CH4: ");
      Serial.print(ch4);
      Serial.print(" ppm");
      Serial.print(" H2: ");
      Serial.print(h2);
      Serial.print(" ppm");
      Serial.print(" C2H5OH: ");
      Serial.print(c2h5oh);
      Serial.println(" ppm");
    #endif
    
    delay(2000);

      #if TEST_MODE
        Serial.println("Ready to send LoRa");
      #endif
      digitalWrite(LED_BUILTIN, HIGH);
        Send_LoRa_Data(mux_code, outside_temperature, outside_CO2, outside_humidity, battery_level,
                    soil_nutrients_N_Nitrogen, soil_nutrients_P_Phosphorus, soil_nutrients_K_Potassium,
                    surface_temperature, surface_humidity,
                    deep_temperature, deep_humidity,
                    light_intensity, light_infrared, light_ultraviolet,
                    R_RGB, G_RGB, B_RGB,
                    pressure, quality, O2,
                    nh3, co, no2, c3h8, c4h10, ch4, h2, c2h5oh);
      digitalWrite(LED_BUILTIN, LOW);
    delay(7500);
        #if TEST_MODE
          Serial.println("finished sending LoRa");
        #endif
    // E-ink display
    delay(500);
    if (!epd.eink_failed) {
    epdText.updateDisplay(mux_code, outside_temperature, outside_CO2, outside_humidity, battery_level,
                            soil_nutrients_N_Nitrogen, soil_nutrients_P_Phosphorus, soil_nutrients_K_Potassium,
                            surface_temperature, surface_humidity,
                            deep_temperature, deep_humidity,
                            light_intensity, light_infrared, light_ultraviolet,
                            R_RGB, G_RGB, B_RGB,
                            pressure, quality, O2,
                            nh3, co, no2, c3h8, c4h10, ch4, h2, c2h5oh);
        #if TEST_MODE
            Serial.println("E-ink updated successfully");
        #endif
    } else {
        #if TEST_MODE
            Serial.println("Skipping E-ink due to previous failure");
        #endif
    }
    
      #if TEST_MODE
        // Serial.println("Finished E-ink display");
        Serial.print("Processing time: ");
        Serial.print(millis()-t);
        Serial.print(" ms ==> ");
        Serial.print((millis()-t)/1000);
        Serial.println(" s");
        Serial.println("==================================================================");
        delay(5000);
      #endif

    // flag = false;//eink
    // delay(7500);  // Comply with transmission constraints (200,000 ms = 3.33 min) => ici toutes les 5 min
    digitalWrite(DONE_PIN, HIGH);
    delay(1);
    digitalWrite(DONE_PIN, LOW);      
    delay(1);
}

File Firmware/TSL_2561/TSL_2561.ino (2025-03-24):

#include <Wire.h>
#include <Adafruit_Sensor.h>
#include <Adafruit_TSL2561_U.h>
   
Adafruit_TSL2561_Unified tsl = Adafruit_TSL2561_Unified(TSL2561_ADDR_FLOAT, 12345);

void displaySensorDetails(void)
{
  sensor_t sensor;
  tsl.getSensor(&sensor);
  Serial.println("------------------------------------");
  Serial.print  ("Sensor:       "); Serial.println(sensor.name);
  Serial.print  ("Driver Ver:   "); Serial.println(sensor.version);
  Serial.print  ("Unique ID:    "); Serial.println(sensor.sensor_id);
  Serial.print  ("Max Value:    "); Serial.print(sensor.max_value); Serial.println(" lux");
  Serial.print  ("Min Value:    "); Serial.print(sensor.min_value); Serial.println(" lux");
  Serial.print  ("Resolution:   "); Serial.print(sensor.resolution); Serial.println(" lux");  
  Serial.println("------------------------------------");
  Serial.println("");
  delay(500);
}

/**************************************************************************/
/*
    Configures the gain and integration time for the TSL2561
*/
/**************************************************************************/
void configureSensor(void)
{
  /* You can also manually set the gain or enable auto-gain support */
  // tsl.setGain(TSL2561_GAIN_1X);      /* No gain ... use in bright light to avoid sensor saturation */
  // tsl.setGain(TSL2561_GAIN_16X);     /* 16x gain ... use in low light to boost sensitivity */
  tsl.enableAutoRange(true);            /* Auto-gain ... switches automatically between 1x and 16x */
  
  /* Changing the integration time gives you better sensor resolution (402ms = 16-bit data) */
  tsl.setIntegrationTime(TSL2561_INTEGRATIONTIME_13MS);      /* fast but low resolution */
  // tsl.setIntegrationTime(TSL2561_INTEGRATIONTIME_101MS);  /* medium resolution and speed   */
  // tsl.setIntegrationTime(TSL2561_INTEGRATIONTIME_402MS);  /* 16-bit data but slowest conversions */

  /* Update these values depending on what you've set above! */  
  Serial.println("------------------------------------");
  Serial.print  ("Gain:         "); Serial.println("Auto");
  Serial.print  ("Timing:       "); Serial.println("13 ms");
  Serial.println("------------------------------------");
}

/**************************************************************************/
/*
    Arduino setup function (automatically called at startup)
*/
/**************************************************************************/
void setup(void) 
{
  Serial.begin(9600);
  Serial.println("Light Sensor Test"); Serial.println("");
  
  /* Initialise the sensor */
  //use tsl.begin() to default to Wire, 
  //tsl.begin(&Wire2) directs api to use Wire2, etc.
  if(!tsl.begin())
  {
    /* There was a problem detecting the TSL2561 ... check your connections */
    Serial.print("Ooops, no TSL2561 detected ... Check your wiring or I2C ADDR!");
    while(1);
  }
  
  /* Display some basic information on this sensor */
  displaySensorDetails();
  
  /* Setup the sensor gain and integration time */
  configureSensor();
  
  /* We're ready to go! */
  Serial.println("");
}

/**************************************************************************/
/*
    Arduino loop function, called once 'setup' is complete (your own code
    should go here)
*/
/**************************************************************************/
void loop(void) 
{  
  /* Get a new sensor event */ 
  sensors_event_t event;
  tsl.getEvent(&event);
 
  /* Display the results (light is measured in lux) */
  if (event.light)
  {
    Serial.print(event.light); Serial.println(" lux");
  }
  else
  {
    /* If event.light = 0 lux the sensor is probably saturated
       and no reliable data could be generated! */
    Serial.println("Sensor overload");
  }
  delay(250);
}

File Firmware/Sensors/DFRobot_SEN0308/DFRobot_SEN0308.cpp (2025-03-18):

#include <Arduino.h>
#include "DFRobot_SEN0308.hpp"

/**
 * @brief Function to initialize the Gravity Soil Moisture Sensor
 * @param analog_pin : GPIO analog pin
 * @return true if a valid value is available. false otherwise
 */
bool SoilMoistureSensor_SEN0308::begin(const uint8_t analog_pin)
{
    _analog_pin = analog_pin;

    return read(false) > 0;
}

/**
 * @brief Function to read the soil moisture value
 * @return The moisture value. A valid reading is between 1 and 3500
 */
uint16_t SoilMoistureSensor_SEN0308::read(bool percentage)
{
    const uint16_t samples = 5; // Fixed number of samples
    const uint16_t delay_ms = 1; // Fixed delay in milliseconds between each sample reading
    uint64_t accumulator = 0;

    for (uint16_t i = 0; i < samples; i++) {
        delay(delay_ms);
        accumulator += analogRead(_analog_pin);
    }

    float value = float(accumulator) / samples;

    if (value > air_humidity)
      value = air_humidity;
    else if (value < water_humidity)
      value = water_humidity;
    // Map the value to a percentage with decimal precision
    float moisturePercent = map(value, air_humidity, water_humidity, 0.0, 100.0);

    // Print the values
    #if TEST_MODE
        Serial.print("Soil Moisture Raw Value: ");
        Serial.print(value);
        Serial.print(" | Moisture: ");
        Serial.print(moisturePercent);
        Serial.println("%");
    #endif

    // Return the raw value for further processing if needed
    return percentage ? moisturePercent : value;
}

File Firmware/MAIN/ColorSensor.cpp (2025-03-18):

#include "ColorSensor.hpp"

// Create a color sensor object
Adafruit_TCS34725 tcs = Adafruit_TCS34725(TCS34725_INTEGRATIONTIME_50MS, TCS34725_GAIN_4X);

bool initColorSensor() {
    return tcs.begin();
}

void readAndNormalizeColor(float* r, float* g, float* b, float* light) {
    uint16_t red, green, blue, light_raw;

    // Read raw data from the sensor
    tcs.setInterrupt(false);  // Turn on LED
    delay(50);
    tcs.getRawData(&red, &green, &blue, &light_raw);
    tcs.setInterrupt(true);   // Turn off LED

    // Store the light intensity value
    *light = (float)light_raw;

    // Normalize RGB values to [0, 255] range
    if (light_raw > 0) {
        *r = ((float)red / light_raw) * 255.0;
        *g = ((float)green / light_raw) * 255.0;
        *b = ((float)blue / light_raw) * 255.0;
    } else {
        *r = *g = *b = 0; // Avoid division by zero
    }

    // Debugging output (only if TEST_MODE is enabled)
    #if TEST_MODE
        Serial.print("Raw -> R: "); Serial.print(red);
        Serial.print(" G: "); Serial.print(green);
        Serial.print(" B: "); Serial.print(blue);
        Serial.print(" Light: "); Serial.println(light_raw);

        Serial.print("Normalized -> R: "); Serial.print(*r);
        Serial.print(" G: "); Serial.print(*g);
        Serial.print(" B: "); Serial.print(*b);
        Serial.print(" Light: "); Serial.println(*light);
    #endif
}

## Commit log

2025-02-14 Udtape security into arduino code - Progress #42
2025-02-14 Security fix mask - Progress #42
    [Transmission_Smart_Farm.ino]
2025-02-14 Security fix mask - Progress #32
    [Transmission_Smart_Farm.ino]
2025-02-16 Add TSL_2561 configuration file
    This file is to configurate the sensor of Lux TSL-2561
2025-02-16 Add the configuration file for Adafruit_TCS34725
    Add the configuration file for the RGB sensor Adafruit_TCS34725
2025-02-17 Firmware transmission compression - Online mode fixed
    [LoRa_Transmission.cpp]
2025-02-17 Modifier les lieus pour les fichier de capture
2025-02-18 Firmware transmission compression + Software decompression - compression_HEX_2 + Battery Level
2025-02-19 Firmware transmission compression + Software decompression - Final bug fix (RGB not included)
    [LoRa_Transmission.cpp]
2025-02-22 Firmware transmission compression - Fix bugs + improve temperature & humidity accuracy + adapt Arduino_KEY for different MKR modules
    [LoRa_Transmission.cpp]
2025-02-25 Sensor - barometer code HP20x v1
2025-02-25 Firmware transmission compression + Software decompression - RGB + Pressure + IR + UV included
2025-02-27 Add DFRobot SEN0308 Soil Moisture Sensor library and example #59
2025-02-27 Firmware Merging Sensor - Pressure + Outside Sensor + RGB + Light v0
2025-02-27 Firmware Merging Sensor - Pressure + Outside Sensor + RGB + Light + Deep-Surface Humidity v1
2025-02-27 Add BatteryManager class for battery monitoring functionality #60
2025-02-27 Firmware Merging Sensor - Pressure + Outside Sensor + RGB + Light + Deep-Surface Humidity+ Voltage v1.1
2025-02-27 Refactor BatteryManager to improve voltage reading and add getter methods for voltage and percentage
2025-02-28 Update the E-ink screen program, the current version can display certain text #61
2025-03-06 Software decompression - Gaz sensors var Initialisation + delay update
2025-03-06 Hardware PCB - PCB v0-v1 + Yulin's circuit diagram
    [B4B-XH-A_LF__SN_.step, MKRWAN_NSK.kicad_pcb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]
2025-03-06 Firmaware compression + Software decompression - Gaz sensors
2025-03-06 Hardware PCB - PCB v2 dispatched section for sensors
    [B4B-XH-A_LF__SN_.step, MKRWAN_NSK.kicad_pcb, MKRWAN_NSK.kicad_sch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]
2025-03-08 Hardware PCB - PCB v4 TTL + Timer + Boster + Level Shifter
    [MKRWAN_NSK.kicad_pcb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]
2025-03-11 Firmaware Sensor - Air contamination + O2 + UV-IR
2025-03-11 Hardware PCB - PCB
    [MKRWAN_NSK.kicad_pcb, MKRWAN_NSK.kicad_sch]
2025-03-18 Update the code and fix the bug for SHT3xSensor. And update the code for the UV_IR sensor #70
    [LoRa_Transmission.cpp, MAIN.ino, Multi_Gaz.cpp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]
2025-03-18 Fix: Fix conflicts between Local and Github
    [DFRobot_SEN0308.ino, MAIN.ino, SEN0385.ino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]
2025-03-18 Backup du dossier Mecanical - Sauvegarde des fichiers FreeCAD
    [v1_Sensor_House_Leaf.FCStd, v2_.FCStd, v3_Sensor_House_Leaf.FCStd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]
2025-03-18 Update Mecanical - v9 version update
    [v1_Sensor_House_Leaf.FCStd, v2_.FCStd, v3_Sensor_House_Leaf.FCStd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]
2025-03-18 Mecanical - v10 + 3D printer files 2 pieces
    [v10_A_Sensor_House_Mushroom.FCStd, v10_B_Sensor_House_Mushroom.FCStd, v10_bis_A_Sensor_House_Mushroom.stl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]
2025-03-21 Hardware PCB_Mushroom - PCB_Mushroom v1 I2C HomeMade Hub
    [PCB_Multi_Outside_Sensor_Onewire.kicad_pcb, PCB_Multi_Outside_Sensor_Onewire.kicad_sch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]
2025-03-21 Hardware PCB - PCB v5 TTL fixed + Holes Alignment
    [MKRWAN_NSK.kicad_pcb, MKRWAN_NSK.kicad_sch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]
2025-03-21 Upgate the code logic of E-ink and added TEST_MODE for Serial.print output #61
2025-03-23 Further configured E-ink, fixed the bug in SHT3x, tested the coordination of E-ink with SHT3x real-time data, integrated E-ink into MAIN.ino and preliminarily removed the bug in the code, waiting for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
    [MAIN.ino, epd2in9b_V3.cpp, epd2in9b_V3.hpp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]
2025-03-24 Rename SEN0332_O2.hpp to SEN0322_O2.hpp
    Fixed a sensor name error
2025-03-24 Rename SEN0332_O2.cpp to SEN0322_O2.cpp
    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
    [SEN0322_O2.cpp]
2025-03-24 Update MAIN.ino
    Fixed the O2 sensor name error
    [MAIN.ino]
2025-04-06 Optimisation de la logique d'attente de l'e-ink
